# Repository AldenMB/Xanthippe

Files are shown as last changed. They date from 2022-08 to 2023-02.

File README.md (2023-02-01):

# Xanthippe

an animated GIF of the Xanthippe circuit running

This is the validation back-end for my TI-30Xa emulator. It is constantly pressing buttons on a TI-30Xa calculator and recording what the LCD shows. The results get stored in an SQLite database. The database is too big to be stored on github, but you can download a CSV from [https://home.aldenbradford.com:58086/](https://home.aldenbradford.com:58086/). In addition, whenever anyone uses the calculator at [https://aldenbradford.com/calculator_emulator/](https://aldenbradford.com/calculator_emulator/) the sequence of button presses is sent to Xanthippe to be tested. It will show up in the database the following day.

For more information about this project, [please see my blog](https://aldenbradford.com/tag/xanthippe.html).

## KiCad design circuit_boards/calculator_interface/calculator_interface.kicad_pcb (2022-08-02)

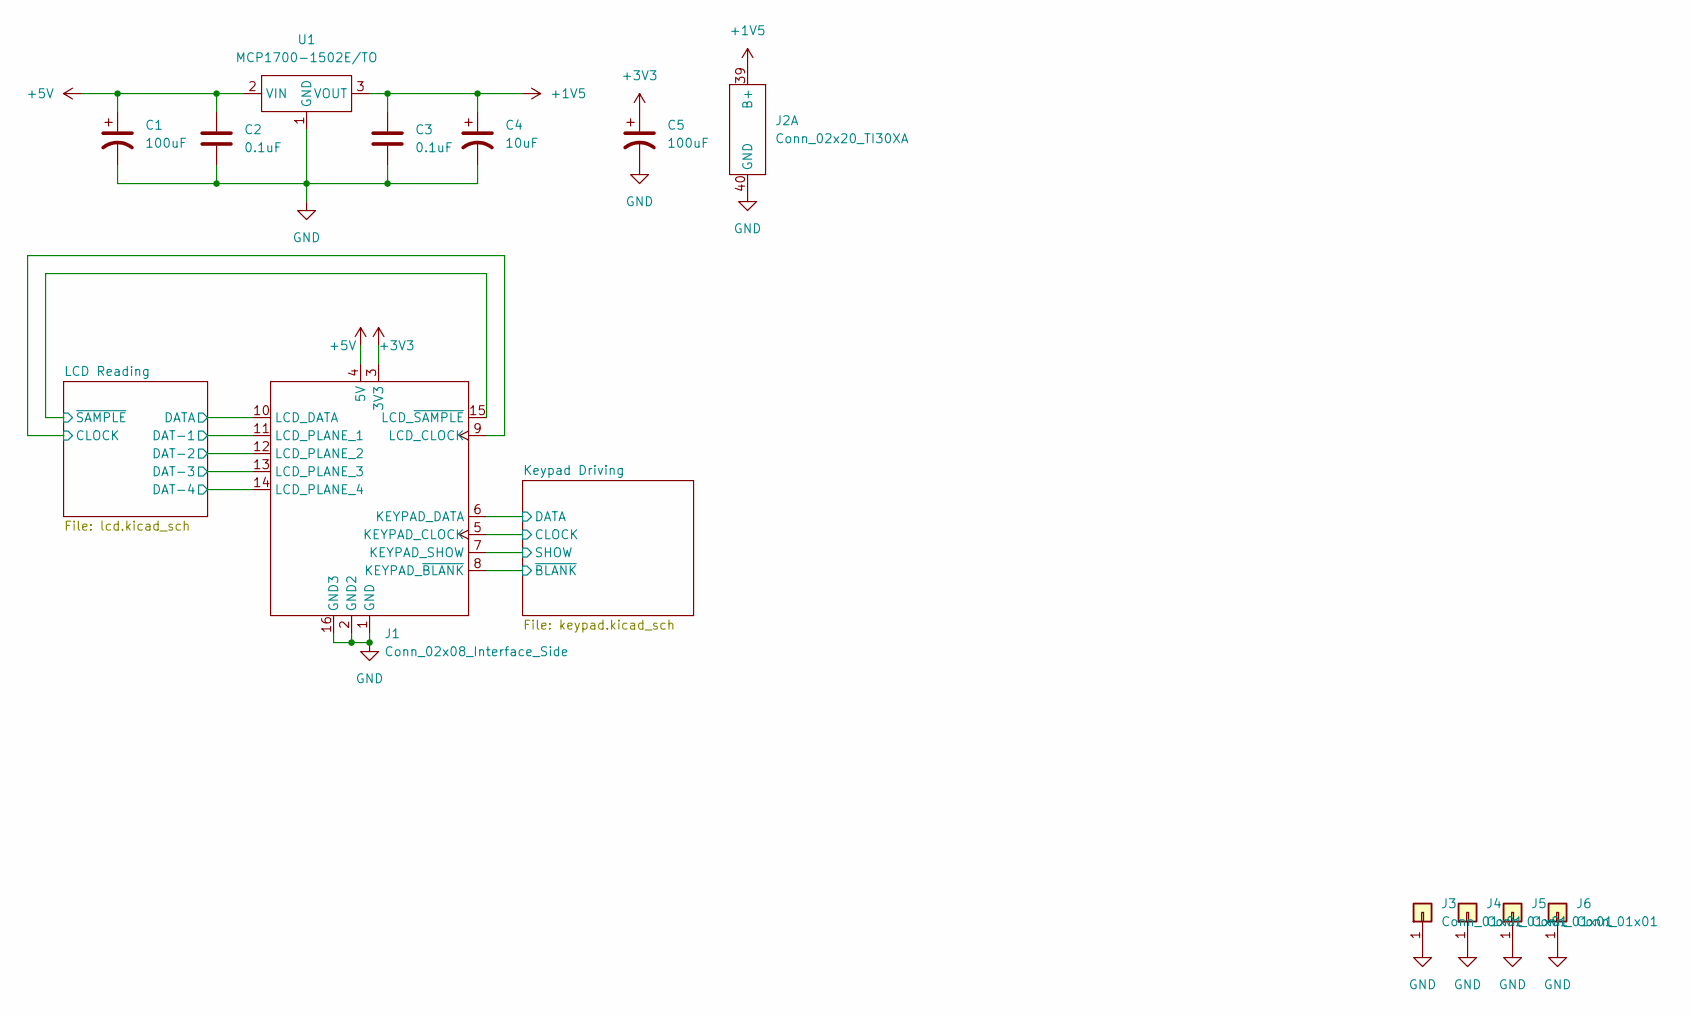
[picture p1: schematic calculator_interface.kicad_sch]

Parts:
C1, C5: 100uF; CP_Radial_D5.0mm_P2.50mm
C2, C3: 0.1uF; C_Disc_D3.8mm_W2.6mm_P2.50mm
C4: 10uF; CP_Radial_D4.0mm_P2.00mm
J1: Conn_02x08_Interface_Side; IDC-Header_2x08_P2.54mm_Vertical
J2: Conn_02x20_TI30XA; IDC-Header_2x20_P2.54mm_Vertical
J3, J4, J5, J6: Conn_01x01; MountingHole_5mm_Pad_Via
U1: MCP1700-1502E/TO; TO-92_Inline

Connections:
+1V5: C3.1, C4.1, J2.39 (B+), U1.3 (VOUT); also elsewhere on the board
+3V3: C5.1, J1.3 (3V3); also elsewhere on the board
+5V: C1.1, C2.1, J1.4 (5V), U1.2 (VIN); also elsewhere on the board
/Keypad Driving/CLOCK: J1.5 (KEYPAD_CLOCK); also elsewhere on the board
/Keypad Driving/DATA: J1.6 (KEYPAD_DATA); also elsewhere on the board
/Keypad Driving/SHOW: J1.7 (KEYPAD_SHOW); also elsewhere on the board
/Keypad Driving/~BLANK: J1.8 (KEYPAD_~BLANK); also elsewhere on the board
/LCD Reading/CLOCK: J1.9 (LCD_CLOCK); also elsewhere on the board
/LCD Reading/DAT-1: J1.11 (LCD_PLANE_1); also elsewhere on the board
/LCD Reading/DAT-2: J1.12 (LCD_PLANE_2); also elsewhere on the board
/LCD Reading/DAT-3: J1.13 (LCD_PLANE_3); also elsewhere on the board
/LCD Reading/DAT-4: J1.14 (LCD_PLANE_4); also elsewhere on the board
/LCD Reading/DATA: J1.10 (LCD_DATA); also elsewhere on the board
/LCD Reading/~SAMPLE: J1.15 (LCD_~SAMPLE); also elsewhere on the board
GND: C1.2, C2.2, C3.2, C4.2, C5.2, J1.1 (GND), J1.2 (GND2), J1.16 (GND3), J2.40 (GND), J3.1, J4.1, J5.1, J6.1, U1.1 (GND); also elsewhere on the board

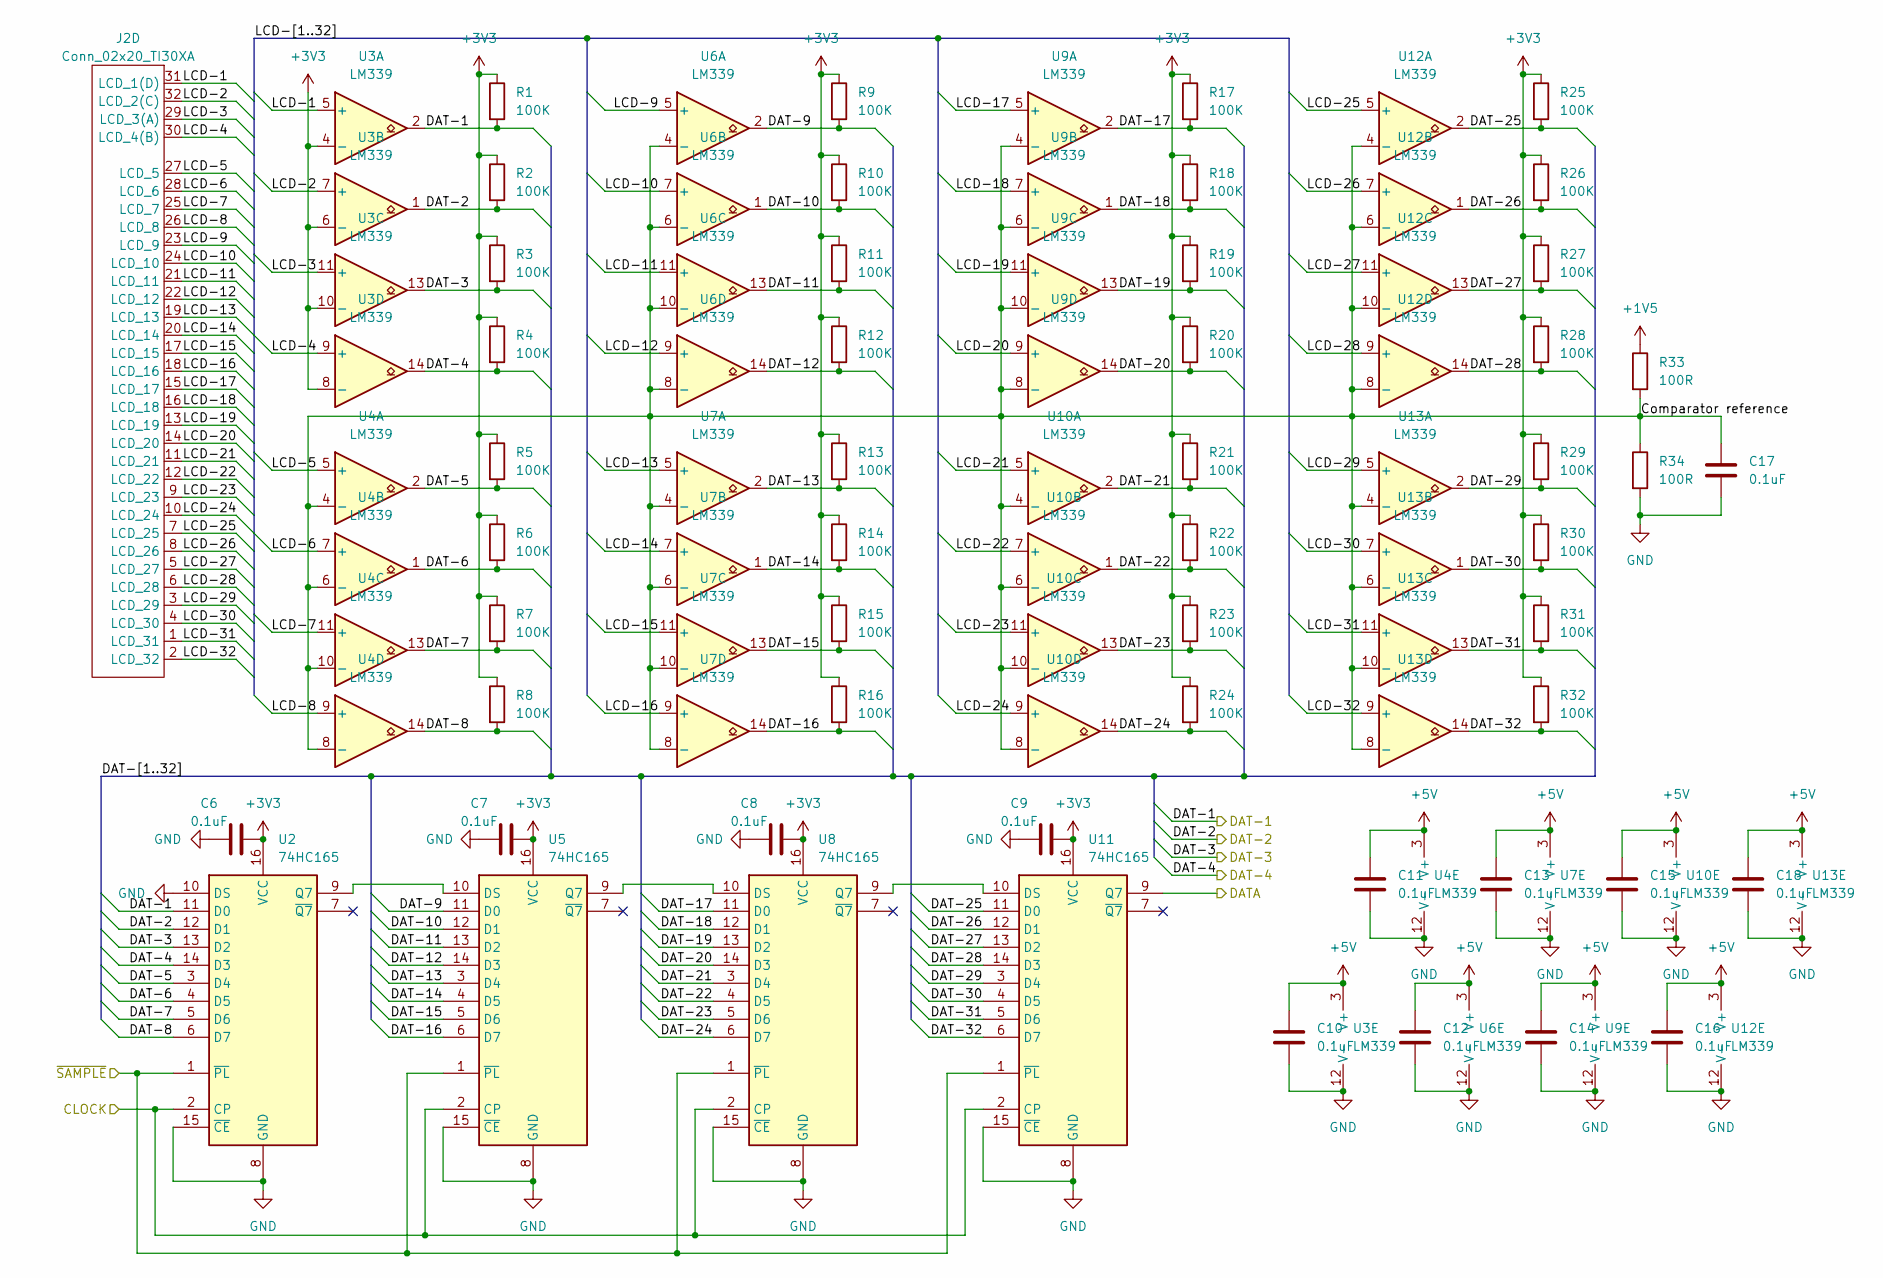
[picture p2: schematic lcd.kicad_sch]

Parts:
C6, C7, C8, C9, C10, C11, C12, C13, C14, C15, C16, C17, C18: 0.1uF; C_Disc_D3.8mm_W2.6mm_P2.50mm
J2: Conn_02x20_TI30XA; IDC-Header_2x20_P2.54mm_Vertical
R1, R2, R3, R4, R5, R6, R7, R8, R9, R10, R11, R12, R13, R14, R15, R16, R17, R18, R19, R20, R21, R22, R23, R24, R25, R26, R27, R28, R29, R30, R31, R32: 100K; R_Axial_DIN0204_L3.6mm_D1.6mm_P7.62mm_Horizontal
R33, R34: 100R; R_Axial_DIN0207_L6.3mm_D2.5mm_P10.16mm_Horizontal
U2, U5, U8, U11: 74HC165; DIP-16_W7.62mm_LongPads
U3, U4, U6, U7, U9, U10, U12, U13: LM339; DIP-14_W7.62mm_LongPads

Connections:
+1V5: R33.1; also elsewhere on the board
+3V3: C6.2, C7.2, C8.2, C9.2, R1.1, R2.1, R3.1, R4.1, R5.1, R6.1, R7.1, R8.1, R9.1, R10.1, R11.1, R12.1, R13.1, R14.1, R15.1, R16.1, R17.1, R18.1, R19.1, R20.1, R21.1, R22.1, R23.1, R24.1, R25.1, R26.1, R27.1, R28.1, R29.1, R30.1, R31.1, R32.1, U2.16 (VCC), U3.4 (-), U3.6 (-), U3.8 (-), U3.10 (-), U5.16 (VCC), U8.16 (VCC), U11.16 (VCC); also elsewhere on the board
+5V: C10.1, C11.1, C12.1, C13.1, C14.1, C15.1, C16.1, C18.1, U3.3 (V+), U4.3 (V+), U6.3 (V+), U7.3 (V+), U9.3 (V+), U10.3 (V+), U12.3 (V+), U13.3 (V+); also elsewhere on the board
/LCD Reading/CLOCK: U2.2 (CP), U5.2 (CP), U8.2 (CP), U11.2 (CP); also elsewhere on the board
/LCD Reading/Comparator reference: C17.1, R33.2, R34.1, U4.4 (-), U4.6 (-), U4.8 (-), U4.10 (-), U6.4 (-), U6.6 (-), U6.8 (-), U6.10 (-), U7.4 (-), U7.6 (-), U7.8 (-), U7.10 (-), U9.4 (-), U9.6 (-), U9.8 (-), U9.10 (-), U10.4 (-), U10.6 (-), U10.8 (-), U10.10 (-), U12.4 (-), U12.6 (-), U12.8 (-), U12.10 (-), U13.4 (-), U13.6 (-), U13.8 (-), U13.10 (-)
/LCD Reading/DAT-1: R1.2, U2.11 (D0), U3.2; also elsewhere on the board
/LCD Reading/DAT-2: R2.2, U2.12 (D1), U3.1; also elsewhere on the board
/LCD Reading/DAT-3: R3.2, U2.13 (D2), U3.13; also elsewhere on the board
/LCD Reading/DAT-4: R4.2, U2.14 (D3), U3.14; also elsewhere on the board
/LCD Reading/DAT-5: R5.2, U2.3 (D4), U4.2
/LCD Reading/DAT-6: R6.2, U2.4 (D5), U4.1
/LCD Reading/DAT-7: R7.2, U2.5 (D6), U4.13
/LCD Reading/DAT-8: R8.2, U2.6 (D7), U4.14
/LCD Reading/DAT-9: R9.2, U5.11 (D0), U6.2
/LCD Reading/DAT-10: R10.2, U5.12 (D1), U6.1
/LCD Reading/DAT-11: R11.2, U5.13 (D2), U6.13
/LCD Reading/DAT-12: R12.2, U5.14 (D3), U6.14
/LCD Reading/DAT-13: R13.2, U5.3 (D4), U7.2
/LCD Reading/DAT-14: R14.2, U5.4 (D5), U7.1
/LCD Reading/DAT-15: R15.2, U5.5 (D6), U7.13
/LCD Reading/DAT-16: R16.2, U5.6 (D7), U7.14
/LCD Reading/DAT-17: R17.2, U8.11 (D0), U9.2
/LCD Reading/DAT-18: R18.2, U8.12 (D1), U9.1
/LCD Reading/DAT-19: R19.2, U8.13 (D2), U9.13
/LCD Reading/DAT-20: R20.2, U8.14 (D3), U9.14
/LCD Reading/DAT-21: R21.2, U8.3 (D4), U10.2
/LCD Reading/DAT-22: R22.2, U8.4 (D5), U10.1
/LCD Reading/DAT-23: R23.2, U8.5 (D6), U10.13
/LCD Reading/DAT-24: R24.2, U8.6 (D7), U10.14
/LCD Reading/DAT-25: R25.2, U11.11 (D0), U12.2
/LCD Reading/DAT-26: R26.2, U11.12 (D1), U12.1
/LCD Reading/DAT-27: R27.2, U11.13 (D2), U12.13
/LCD Reading/DAT-28: R28.2, U11.14 (D3), U12.14
/LCD Reading/DAT-29: R29.2, U11.3 (D4), U13.2
/LCD Reading/DAT-30: R30.2, U11.4 (D5), U13.1
/LCD Reading/DAT-31: R31.2, U11.5 (D6), U13.13
/LCD Reading/DAT-32: R32.2, U11.6 (D7), U13.14
/LCD Reading/DATA: U11.9 (Q7); also elsewhere on the board
/LCD Reading/LCD-1: J2.31 (LCD_1(D)), U3.5 (+)
/LCD Reading/LCD-2: J2.32 (LCD_2(C)), U3.7 (+)
/LCD Reading/LCD-3: J2.29 (LCD_3(A)), U3.11 (+)
/LCD Reading/LCD-4: J2.30 (LCD_4(B)), U3.9 (+)
/LCD Reading/LCD-5: J2.27 (LCD_5), U4.5 (+)
/LCD Reading/LCD-6: J2.28 (LCD_6), U4.7 (+)
/LCD Reading/LCD-7: J2.25 (LCD_7), U4.11 (+)
/LCD Reading/LCD-8: J2.26 (LCD_8), U4.9 (+)
/LCD Reading/LCD-9: J2.23 (LCD_9), U6.5 (+)
/LCD Reading/LCD-10: J2.24 (LCD_10), U6.7 (+)
/LCD Reading/LCD-11: J2.21 (LCD_11), U6.11 (+)
/LCD Reading/LCD-12: J2.22 (LCD_12), U6.9 (+)
/LCD Reading/LCD-13: J2.19 (LCD_13), U7.5 (+)
/LCD Reading/LCD-14: J2.20 (LCD_14), U7.7 (+)
/LCD Reading/LCD-15: J2.17 (LCD_15), U7.11 (+)
/LCD Reading/LCD-16: J2.18 (LCD_16), U7.9 (+)
/LCD Reading/LCD-17: J2.15 (LCD_17), U9.5 (+)
/LCD Reading/LCD-18: J2.16 (LCD_18), U9.7 (+)
/LCD Reading/LCD-19: J2.13 (LCD_19), U9.11 (+)
/LCD Reading/LCD-20: J2.14 (LCD_20), U9.9 (+)
/LCD Reading/LCD-21: J2.11 (LCD_21), U10.5 (+)
/LCD Reading/LCD-22: J2.12 (LCD_22), U10.7 (+)
/LCD Reading/LCD-23: J2.9 (LCD_23), U10.11 (+)
/LCD Reading/LCD-24: J2.10 (LCD_24), U10.9 (+)
/LCD Reading/LCD-25: J2.7 (LCD_25), U12.5 (+)
/LCD Reading/LCD-26: J2.8 (LCD_26), U12.7 (+)
/LCD Reading/LCD-27: J2.5 (LCD_27), U12.11 (+)
/LCD Reading/LCD-28: J2.6 (LCD_28), U12.9 (+)
/LCD Reading/LCD-29: J2.3 (LCD_29), U13.5 (+)
/LCD Reading/LCD-30: J2.4 (LCD_30), U13.7 (+)
/LCD Reading/LCD-31: J2.1 (LCD_31), U13.11 (+)
/LCD Reading/LCD-32: J2.2 (LCD_32), U13.9 (+)
/LCD Reading/~SAMPLE: U2.1 (~PL), U5.1 (~PL), U8.1 (~PL), U11.1 (~PL); also elsewhere on the board
GND: C6.1, C7.1, C8.1, C9.1, C10.2, C11.2, C12.2, C13.2, C14.2, C15.2, C16.2, C17.2, C18.2, R34.2, U2.8 (GND), U2.10 (DS), U2.15 (~CE), U3.12 (V-), U4.12 (V-), U5.8 (GND), U5.15 (~CE), U6.12 (V-), U7.12 (V-), U8.8 (GND), U8.15 (~CE), U9.12 (V-), U10.12 (V-), U11.8 (GND), U11.15 (~CE), U12.12 (V-), U13.12 (V-); also elsewhere on the board
unnamed: U2.9 (Q7), U5.10 (DS)
unnamed: U5.9 (Q7), U8.10 (DS)
unnamed: U8.9 (Q7), U11.10 (DS)

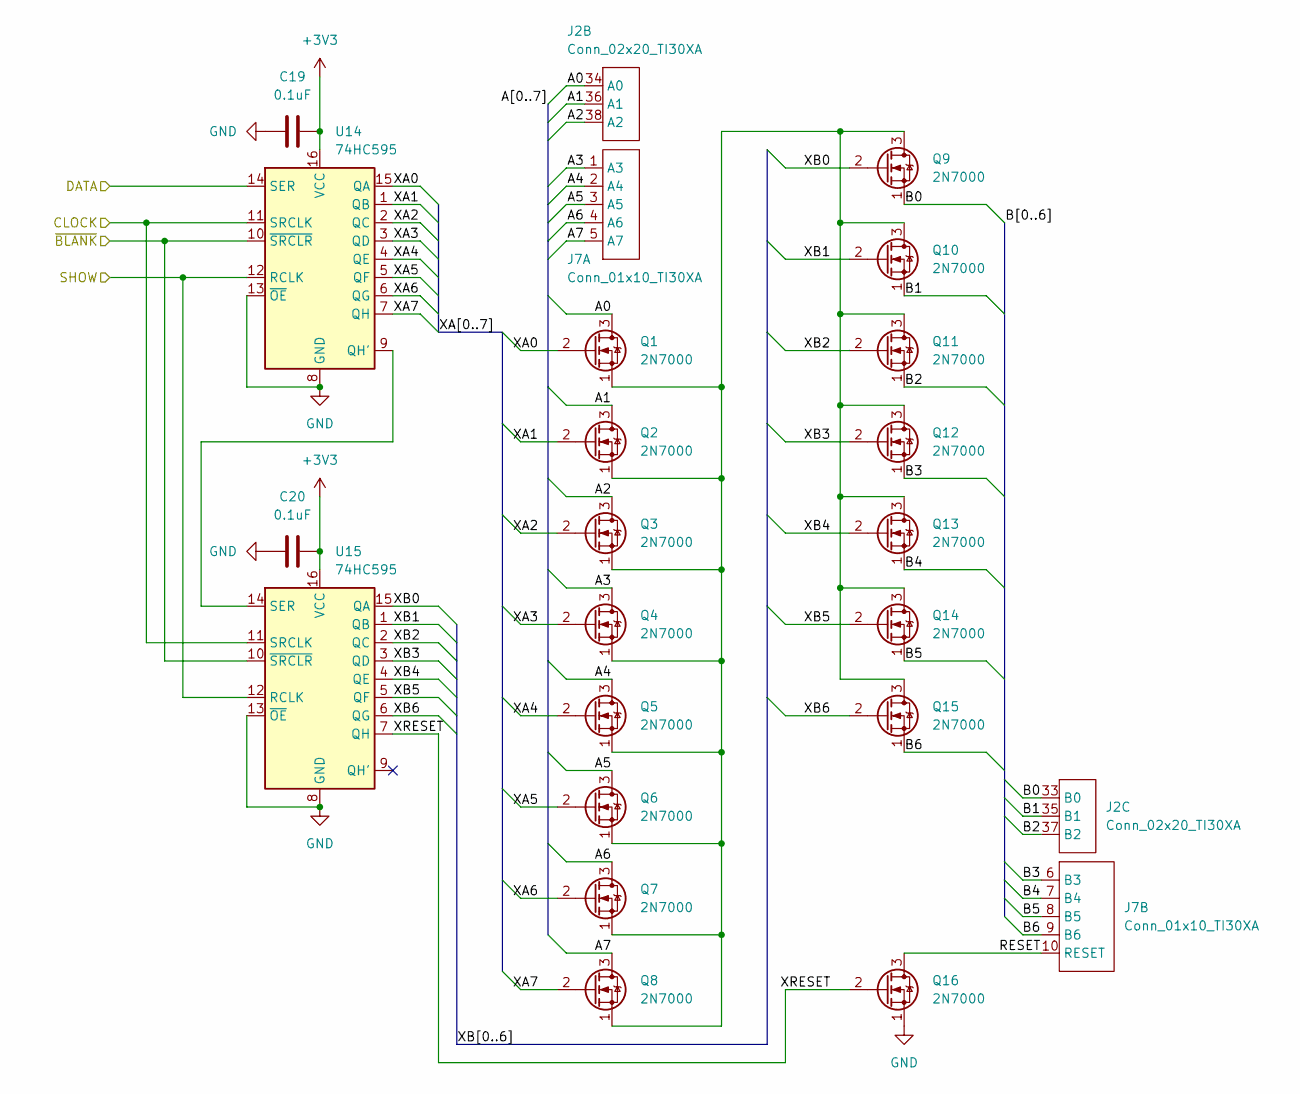
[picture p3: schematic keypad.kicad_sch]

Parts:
C19, C20: 0.1uF; C_Disc_D3.8mm_W2.6mm_P2.50mm
J2: Conn_02x20_TI30XA; IDC-Header_2x20_P2.54mm_Vertical
J7: Conn_01x10_TI30XA; PinHeader_1x10_P2.54mm_Horizontal
Q1, Q2, Q3, Q4, Q5, Q6, Q7, Q8, Q9, Q10, Q11, Q12, Q13, Q14, Q15, Q16: 2N7000; TO-92_Inline
U14, U15: 74HC595; DIP-16_W7.62mm_LongPads

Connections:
+3V3: C19.2, C20.1, U14.16 (VCC), U15.16 (VCC); also elsewhere on the board
/Keypad Driving/A0: J2.34 (A0), Q1.3 (D)
/Keypad Driving/A1: J2.36 (A1), Q2.3 (D)
/Keypad Driving/A2: J2.38 (A2), Q3.3 (D)
/Keypad Driving/A3: J7.1 (A3), Q4.3 (D)
/Keypad Driving/A4: J7.2 (A4), Q5.3 (D)
/Keypad Driving/A5: J7.3 (A5), Q6.3 (D)
/Keypad Driving/A6: J7.4 (A6), Q7.3 (D)
/Keypad Driving/A7: J7.5 (A7), Q8.3 (D)
/Keypad Driving/B0: J2.33 (B0), Q9.1 (S)
/Keypad Driving/B1: J2.35 (B1), Q10.1 (S)
/Keypad Driving/B2: J2.37 (B2), Q11.1 (S)
/Keypad Driving/B3: J7.6 (B3), Q12.1 (S)
/Keypad Driving/B4: J7.7 (B4), Q13.1 (S)
/Keypad Driving/B5: J7.8 (B5), Q14.1 (S)
/Keypad Driving/B6: J7.9 (B6), Q15.1 (S)
/Keypad Driving/CLOCK: U14.11 (SRCLK), U15.11 (SRCLK); also elsewhere on the board
/Keypad Driving/DATA: U14.14 (SER); also elsewhere on the board
/Keypad Driving/RESET: J7.10 (RESET), Q16.3 (D)
/Keypad Driving/SHOW: U14.12 (RCLK), U15.12 (RCLK); also elsewhere on the board
/Keypad Driving/XA0: Q1.2 (G), U14.15 (QA)
/Keypad Driving/XA1: Q2.2 (G), U14.1 (QB)
/Keypad Driving/XA2: Q3.2 (G), U14.2 (QC)
/Keypad Driving/XA3: Q4.2 (G), U14.3 (QD)
/Keypad Driving/XA4: Q5.2 (G), U14.4 (QE)
/Keypad Driving/XA5: Q6.2 (G), U14.5 (QF)
/Keypad Driving/XA6: Q7.2 (G), U14.6 (QG)
/Keypad Driving/XA7: Q8.2 (G), U14.7 (QH)
/Keypad Driving/XB0: Q9.2 (G), U15.15 (QA)
/Keypad Driving/XB1: Q10.2 (G), U15.1 (QB)
/Keypad Driving/XB2: Q11.2 (G), U15.2 (QC)
/Keypad Driving/XB3: Q12.2 (G), U15.3 (QD)
/Keypad Driving/XB4: Q13.2 (G), U15.4 (QE)
/Keypad Driving/XB5: Q14.2 (G), U15.5 (QF)
/Keypad Driving/XB6: Q15.2 (G), U15.6 (QG)
/Keypad Driving/XRESET: Q16.2 (G), U15.7 (QH)
/Keypad Driving/~BLANK: U14.10 (~SRCLR), U15.10 (~SRCLR); also elsewhere on the board
GND: C19.1, C20.2, Q16.1 (S), U14.8 (GND), U14.13 (~OE), U15.8 (GND), U15.13 (~OE); also elsewhere on the board
unnamed: Q1.1 (S), Q2.1 (S), Q3.1 (S), Q4.1 (S), Q5.1 (S), Q6.1 (S), Q7.1 (S), Q8.1 (S), Q9.3 (D), Q10.3 (D), Q11.3 (D), Q12.3 (D), Q13.3 (D), Q14.3 (D), Q15.3 (D)
unnamed: U14.9 (QH'), U15.14 (SER)

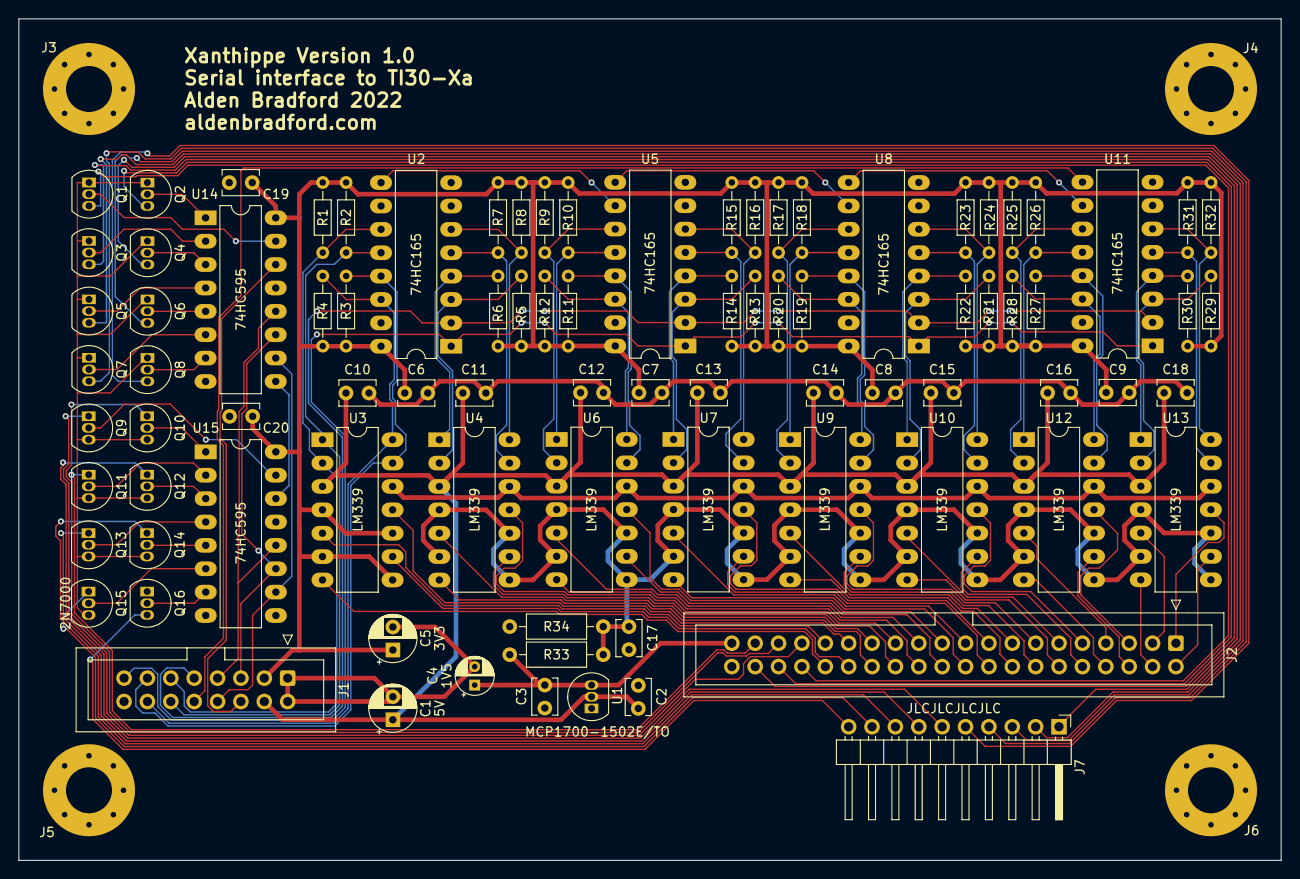
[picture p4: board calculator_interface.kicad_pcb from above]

Board: 2 copper layers, 137.2 x 91.4 mm, 92 parts (0 on the bottom side), 113 nets.

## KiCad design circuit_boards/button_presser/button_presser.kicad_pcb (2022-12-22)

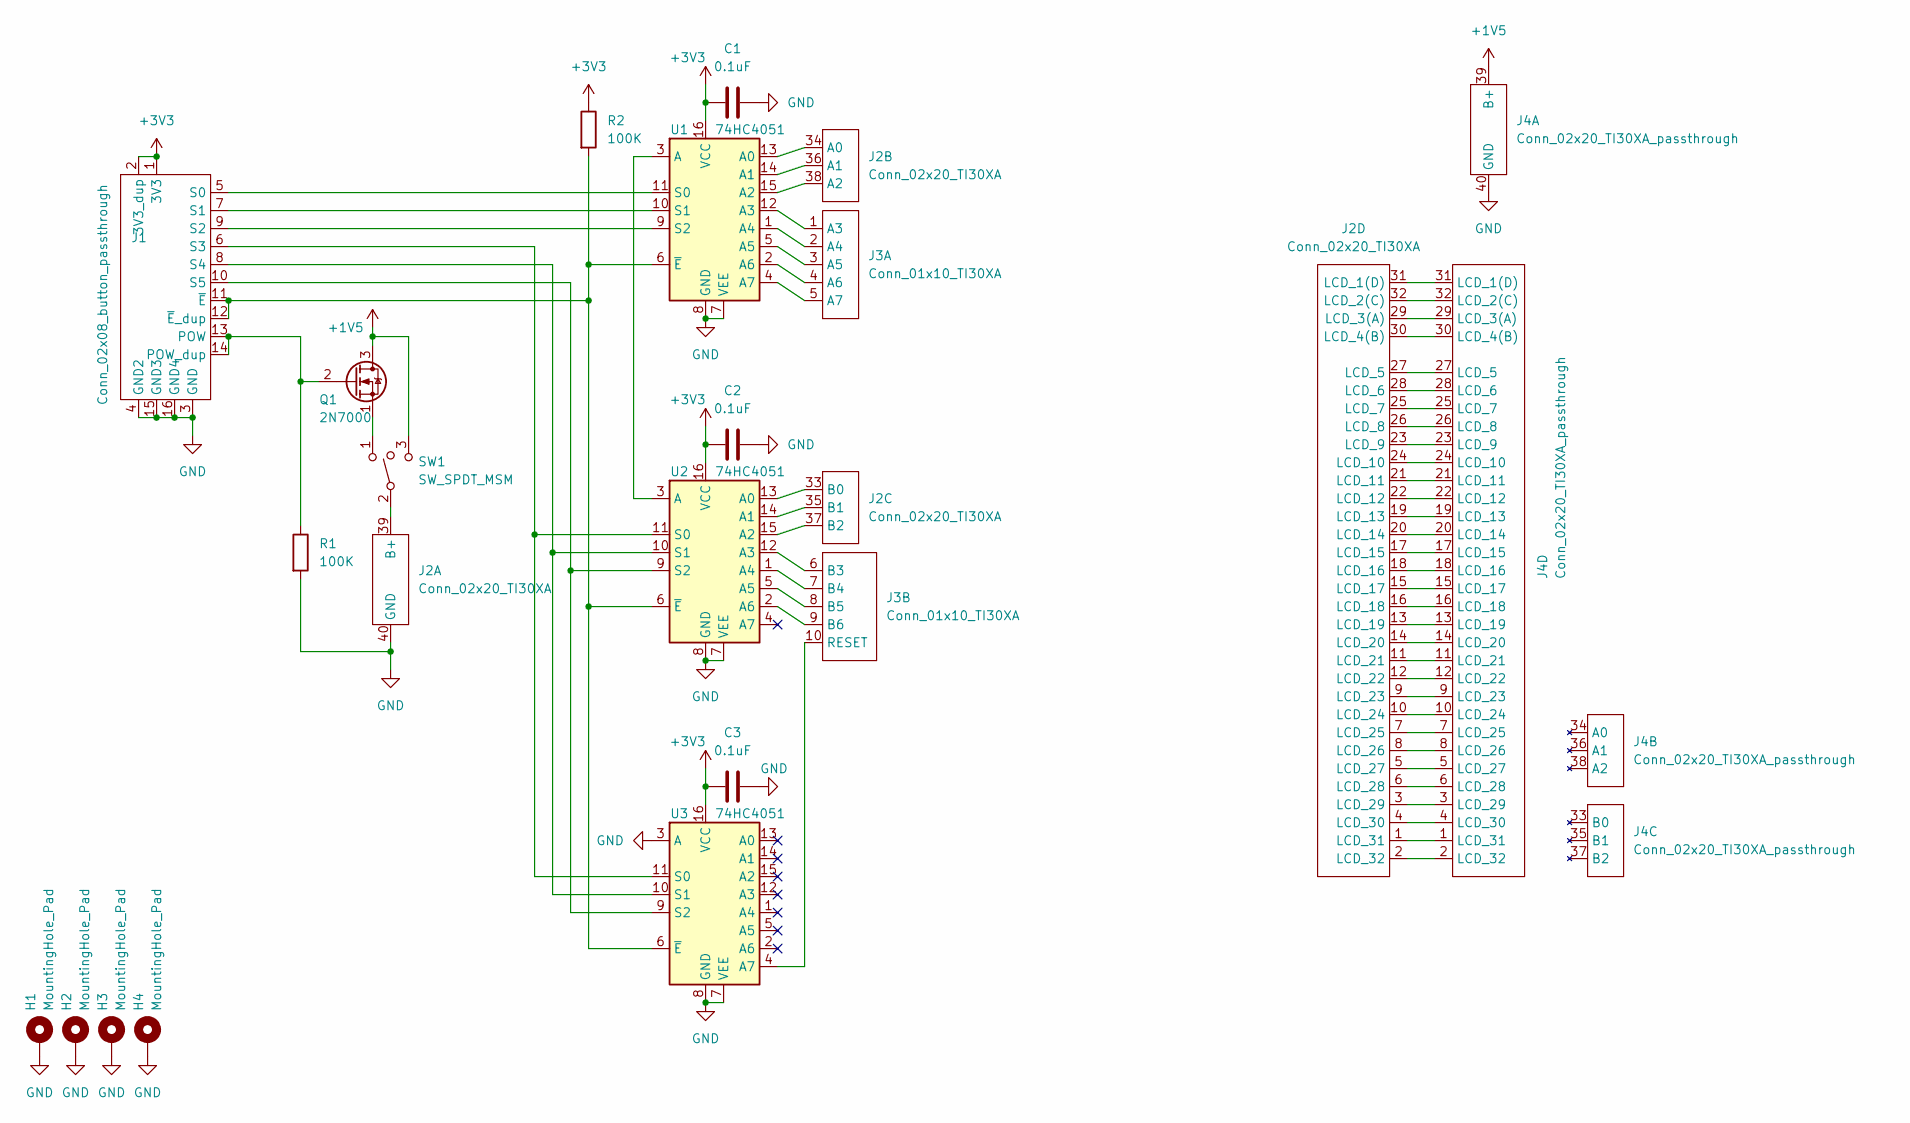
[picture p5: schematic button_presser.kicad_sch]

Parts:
C1, C2, C3: 0.1uF; C_Disc_D5.0mm_W2.5mm_P2.50mm
H1, H2, H3, H4: MountingHole_Pad; MountingHole_5mm_Pad_Via
J1: Conn_02x08_button_passthrough; IDC-Header_2x08_P2.54mm_Vertical
J2: Conn_02x20_TI30XA; IDC-Header_2x20_P2.54mm_Vertical
J3: Conn_01x10_TI30XA; PinHeader_1x10_P2.54mm_Horizontal
J4: Conn_02x20_TI30XA_passthrough; IDC-Header_2x20_P2.54mm_Vertical
Q1: 2N7000; TO-92_Inline_Wide
R1, R2: 100K; R_Axial_DIN0411_L9.9mm_D3.6mm_P15.24mm_Horizontal
SW1: SW_SPDT_MSM; Switch_Jumper
U1, U2, U3: 74HC4051; DIP-16_W7.62mm_LongPads

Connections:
+1V5: J4.39 (B+), Q1.3 (D), SW1.3
+3V3: C1.1, C2.1, C3.1, J1.1 (3V3), J1.2 (3V3_dup), R2.1, U1.16 (VCC), U2.16 (VCC), U3.16 (VCC)
GND: C1.2, C2.2, C3.2, H1.1, H2.1, H3.1, H4.1, J1.3 (GND), J1.4 (GND2), J1.15 (GND3), J1.16 (GND4), J2.40 (GND), J4.40 (GND), R1.2, U1.7 (VEE), U1.8 (GND), U2.7 (VEE), U2.8 (GND), U3.3 (A), U3.7 (VEE), U3.8 (GND)
unnamed: J1.5 (S0), U1.11 (S0)
unnamed: J1.6 (S3), U2.11 (S0), U3.11 (S0)
unnamed: J1.7 (S1), U1.10 (S1)
unnamed: J1.8 (S4), U2.10 (S1), U3.10 (S1)
unnamed: J1.9 (S2), U1.9 (S2)
unnamed: J1.10 (S5), U2.9 (S2), U3.9 (S2)
unnamed: J1.11 (~E), J1.12 (~E_dup), R2.2, U1.6 (~E), U2.6 (~E), U3.6 (~E)
unnamed: J1.13 (POW), J1.14 (POW_dup), Q1.2 (G), R1.1
unnamed: J2.1 (LCD_31), J4.1 (LCD_31)
unnamed: J2.2 (LCD_32), J4.2 (LCD_32)
unnamed: J2.3 (LCD_29), J4.3 (LCD_29)
unnamed: J2.4 (LCD_30), J4.4 (LCD_30)
unnamed: J2.5 (LCD_27), J4.5 (LCD_27)
unnamed: J2.6 (LCD_28), J4.6 (LCD_28)
unnamed: J2.7 (LCD_25), J4.7 (LCD_25)
unnamed: J2.8 (LCD_26), J4.8 (LCD_26)
unnamed: J2.9 (LCD_23), J4.9 (LCD_23)
unnamed: J2.10 (LCD_24), J4.10 (LCD_24)
unnamed: J2.11 (LCD_21), J4.11 (LCD_21)
unnamed: J2.12 (LCD_22), J4.12 (LCD_22)
unnamed: J2.13 (LCD_19), J4.13 (LCD_19)
unnamed: J2.14 (LCD_20), J4.14 (LCD_20)
unnamed: J2.15 (LCD_17), J4.15 (LCD_17)
unnamed: J2.16 (LCD_18), J4.16 (LCD_18)
unnamed: J2.17 (LCD_15), J4.17 (LCD_15)
unnamed: J2.18 (LCD_16), J4.18 (LCD_16)
unnamed: J2.19 (LCD_13), J4.19 (LCD_13)
unnamed: J2.20 (LCD_14), J4.20 (LCD_14)
unnamed: J2.21 (LCD_11), J4.21 (LCD_11)
unnamed: J2.22 (LCD_12), J4.22 (LCD_12)
unnamed: J2.23 (LCD_9), J4.23 (LCD_9)
unnamed: J2.24 (LCD_10), J4.24 (LCD_10)
unnamed: J2.25 (LCD_7), J4.25 (LCD_7)
unnamed: J2.26 (LCD_8), J4.26 (LCD_8)
unnamed: J2.27 (LCD_5), J4.27 (LCD_5)
unnamed: J2.28 (LCD_6), J4.28 (LCD_6)
unnamed: J2.29 (LCD_3(A)), J4.29 (LCD_3(A))
unnamed: J2.30 (LCD_4(B)), J4.30 (LCD_4(B))
unnamed: J2.31 (LCD_1(D)), J4.31 (LCD_1(D))
unnamed: J2.32 (LCD_2(C)), J4.32 (LCD_2(C))
unnamed: J2.33 (B0), U2.13 (A0)
unnamed: J2.34 (A0), U1.13 (A0)
unnamed: J2.35 (B1), U2.14 (A1)
unnamed: J2.36 (A1), U1.14 (A1)
unnamed: J2.37 (B2), U2.15 (A2)
unnamed: J2.38 (A2), U1.15 (A2)
unnamed: J2.39 (B+), SW1.2
unnamed: J3.1 (A3), U1.12 (A3)
unnamed: J3.2 (A4), U1.1 (A4)
unnamed: J3.3 (A5), U1.5 (A5)
unnamed: J3.4 (A6), U1.2 (A6)
unnamed: J3.5 (A7), U1.4 (A7)
unnamed: J3.6 (B3), U2.12 (A3)
unnamed: J3.7 (B4), U2.1 (A4)
unnamed: J3.8 (B5), U2.5 (A5)
unnamed: J3.9 (B6), U2.2 (A6)
unnamed: J3.10 (RESET), U3.4 (A7)
unnamed: Q1.1 (S), SW1.1
unnamed: U1.3 (A), U2.3 (A)

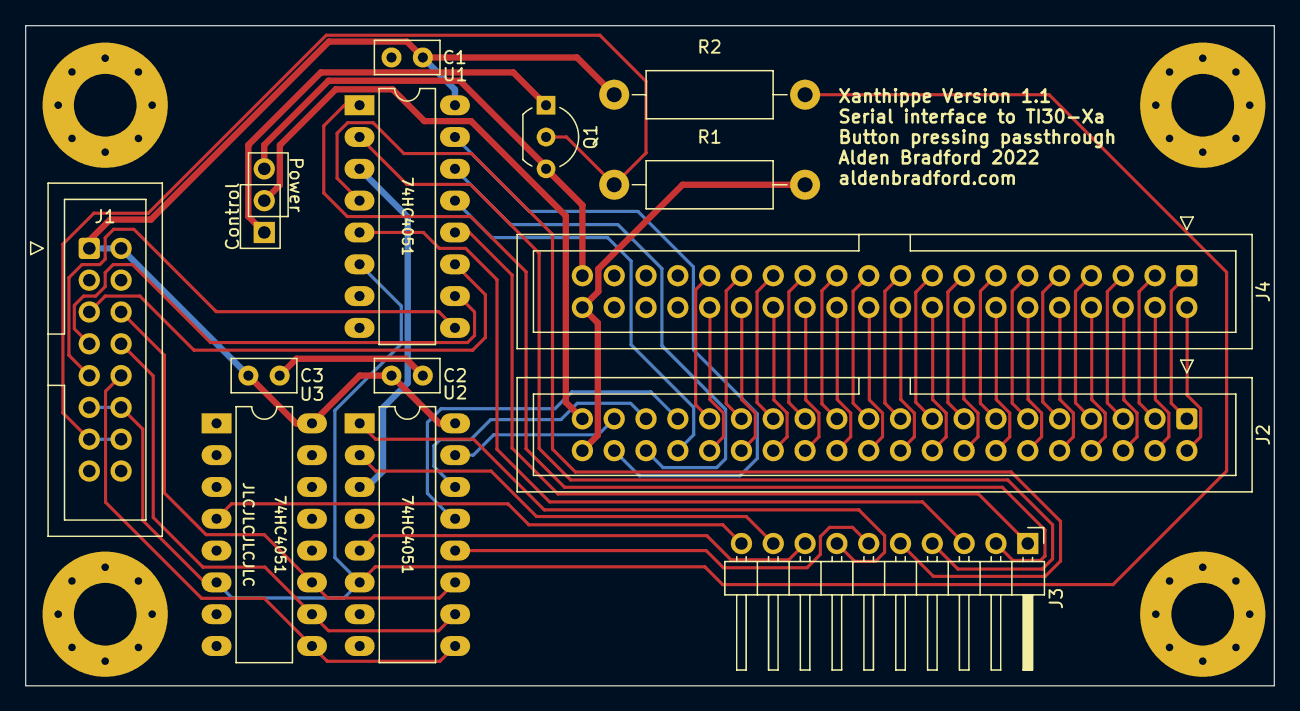
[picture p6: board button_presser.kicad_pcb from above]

Board: 2 copper layers, 99.7 x 52.7 mm, 18 parts (0 on the bottom side), 62 nets.

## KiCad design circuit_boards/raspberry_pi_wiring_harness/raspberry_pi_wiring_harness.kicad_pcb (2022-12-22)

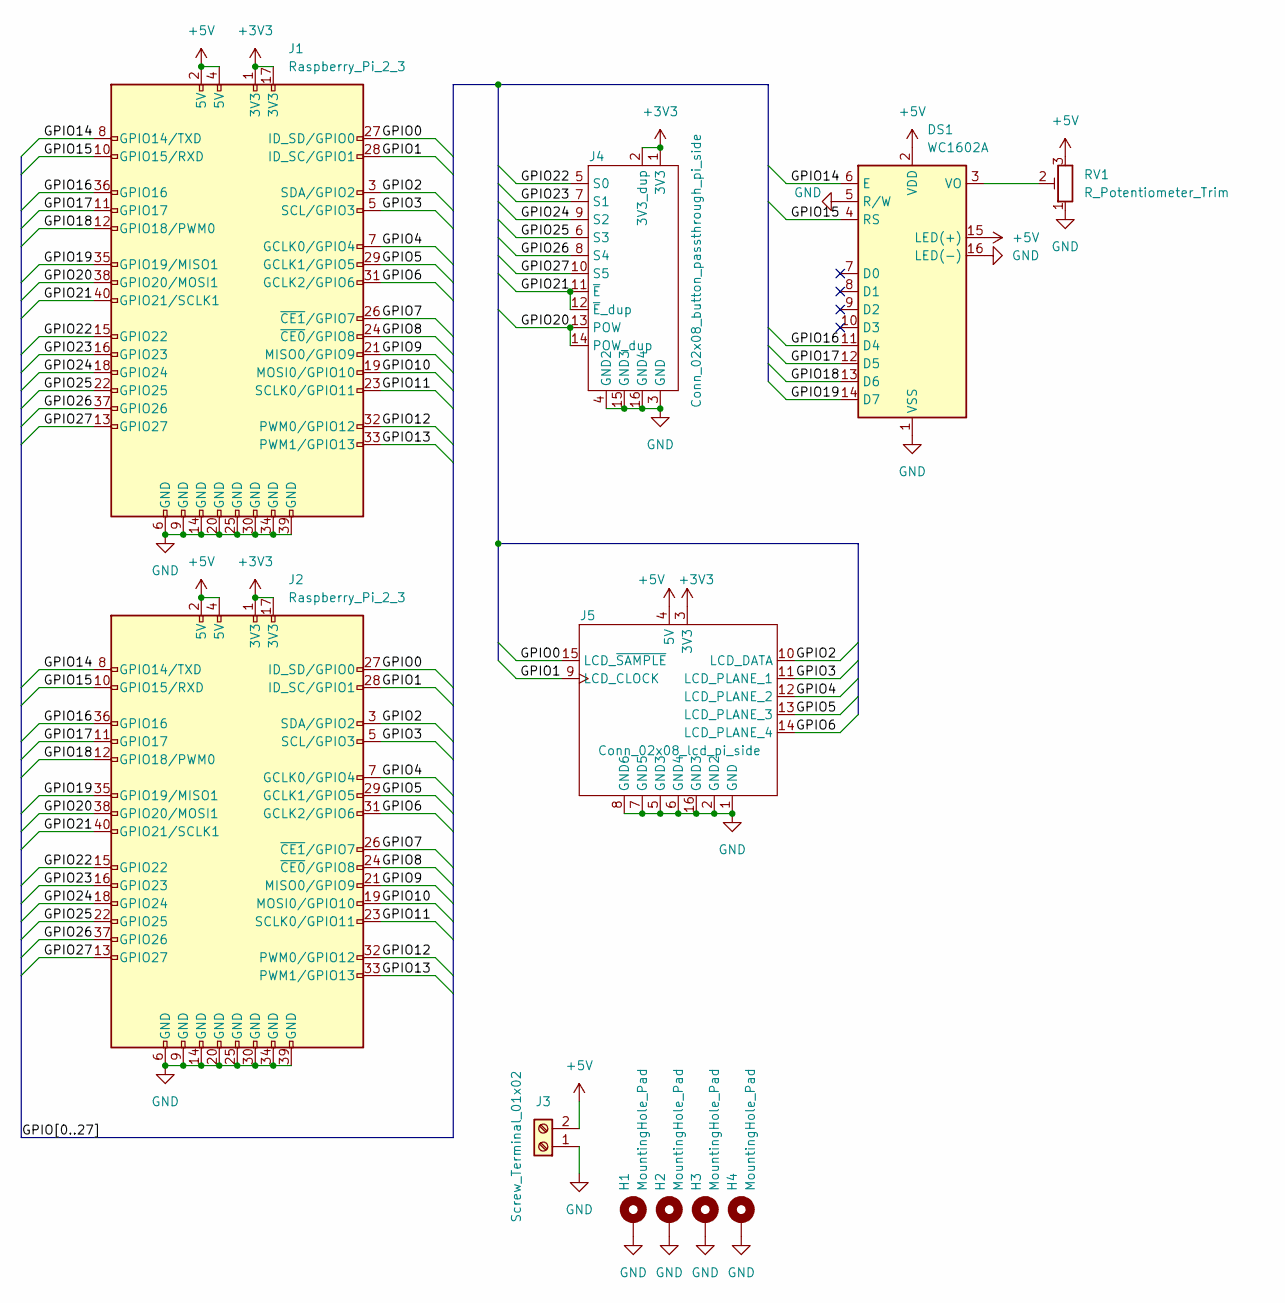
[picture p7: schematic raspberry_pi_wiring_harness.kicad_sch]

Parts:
DS1: WC1602A
H1, H2, H3, H4: MountingHole_Pad; MountingHole_5mm_Pad_Via
J1, J2: Raspberry_Pi_2_3; IDC-Header_2x20_P2.54mm_Vertical
J3: Screw_Terminal_01x02; TerminalBlock_bornier-2_P5.08mm
J4: Conn_02x08_button_passthrough_pi_side; IDC-Header_2x08_P2.54mm_Vertical
J5: Conn_02x08_lcd_pi_side; IDC-Header_2x08_P2.54mm_Vertical
RV1: R_Potentiometer_Trim; Potentiometer_Bourns_3296W_Vertical

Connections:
+3V3: J1.1 (3V3), J1.17 (3V3), J2.1 (3V3), J2.17 (3V3), J4.1 (3V3), J4.2 (3V3_dup), J5.3 (3V3)
+5V: DS1.2 (VDD), DS1.15 (LED(+)), J1.2 (5V), J1.4 (5V), J2.2 (5V), J2.4 (5V), J3.2, J5.4 (5V), RV1.3
/GPIO0: J1.27 (ID_SD/GPIO0), J2.27 (ID_SD/GPIO0), J5.15 (LCD_~SAMPLE)
/GPIO1: J1.28 (ID_SC/GPIO1), J2.28 (ID_SC/GPIO1), J5.9 (LCD_CLOCK)
/GPIO2: J1.3 (SDA/GPIO2), J2.3 (SDA/GPIO2), J5.10 (LCD_DATA)
/GPIO3: J1.5 (SCL/GPIO3), J2.5 (SCL/GPIO3), J5.11 (LCD_PLANE_1)
/GPIO4: J1.7 (GCLK0/GPIO4), J2.7 (GCLK0/GPIO4), J5.12 (LCD_PLANE_2)
/GPIO5: J1.29 (GCLK1/GPIO5), J2.29 (GCLK1/GPIO5), J5.13 (LCD_PLANE_3)
/GPIO6: J1.31 (GCLK2/GPIO6), J2.31 (GCLK2/GPIO6), J5.14 (LCD_PLANE_4)
/GPIO7: J1.26 (~CE1/GPIO7), J2.26 (~CE1/GPIO7)
/GPIO8: J1.24 (~CE0/GPIO8), J2.24 (~CE0/GPIO8)
/GPIO9: J1.21 (MISO0/GPIO9), J2.21 (MISO0/GPIO9)
/GPIO10: J1.19 (MOSI0/GPIO10), J2.19 (MOSI0/GPIO10)
/GPIO11: J1.23 (SCLK0/GPIO11), J2.23 (SCLK0/GPIO11)
/GPIO12: J1.32 (PWM0/GPIO12), J2.32 (PWM0/GPIO12)
/GPIO13: J1.33 (PWM1/GPIO13), J2.33 (PWM1/GPIO13)
/GPIO14: DS1.6 (E), J1.8 (GPIO14/TXD), J2.8 (GPIO14/TXD)
/GPIO15: DS1.4 (RS), J1.10 (GPIO15/RXD), J2.10 (GPIO15/RXD)
/GPIO16: DS1.11 (D4), J1.36 (GPIO16), J2.36 (GPIO16)
/GPIO17: DS1.12 (D5), J1.11 (GPIO17), J2.11 (GPIO17)
/GPIO18: DS1.13 (D6), J1.12 (GPIO18/PWM0), J2.12 (GPIO18/PWM0)
/GPIO19: DS1.14 (D7), J1.35 (GPIO19/MISO1), J2.35 (GPIO19/MISO1)
/GPIO20: J1.38 (GPIO20/MOSI1), J2.38 (GPIO20/MOSI1), J4.13 (POW), J4.14 (POW_dup)
/GPIO21: J1.40 (GPIO21/SCLK1), J2.40 (GPIO21/SCLK1), J4.11 (~E), J4.12 (~E_dup)
/GPIO22: J1.15 (GPIO22), J2.15 (GPIO22), J4.5 (S0)
/GPIO23: J1.16 (GPIO23), J2.16 (GPIO23), J4.7 (S1)
/GPIO24: J1.18 (GPIO24), J2.18 (GPIO24), J4.9 (S2)
/GPIO25: J1.22 (GPIO25), J2.22 (GPIO25), J4.6 (S3)
/GPIO26: J1.37 (GPIO26), J2.37 (GPIO26), J4.8 (S4)
/GPIO27: J1.13 (GPIO27), J2.13 (GPIO27), J4.10 (S5)
GND: DS1.1 (VSS), DS1.5 (R/W), DS1.16 (LED(-)), H1.1, H2.1, H3.1, H4.1, J1.6 (GND), J1.9 (GND), J1.14 (GND), J1.20 (GND), J1.25 (GND), J1.30 (GND), J1.34 (GND), J1.39 (GND), J2.6 (GND), J2.9 (GND), J2.14 (GND), J2.20 (GND), J2.25 (GND), J2.30 (GND), J2.34 (GND), J2.39 (GND), J3.1, J4.3 (GND), J4.4 (GND2), J4.15 (GND3), J4.16 (GND4), J5.1 (GND), J5.2 (GND2), J5.5 (GND3), J5.6 (GND4), J5.7 (GND5), J5.8 (GND6), J5.16 (GND3), RV1.1
unnamed: DS1.3 (VO), RV1.2

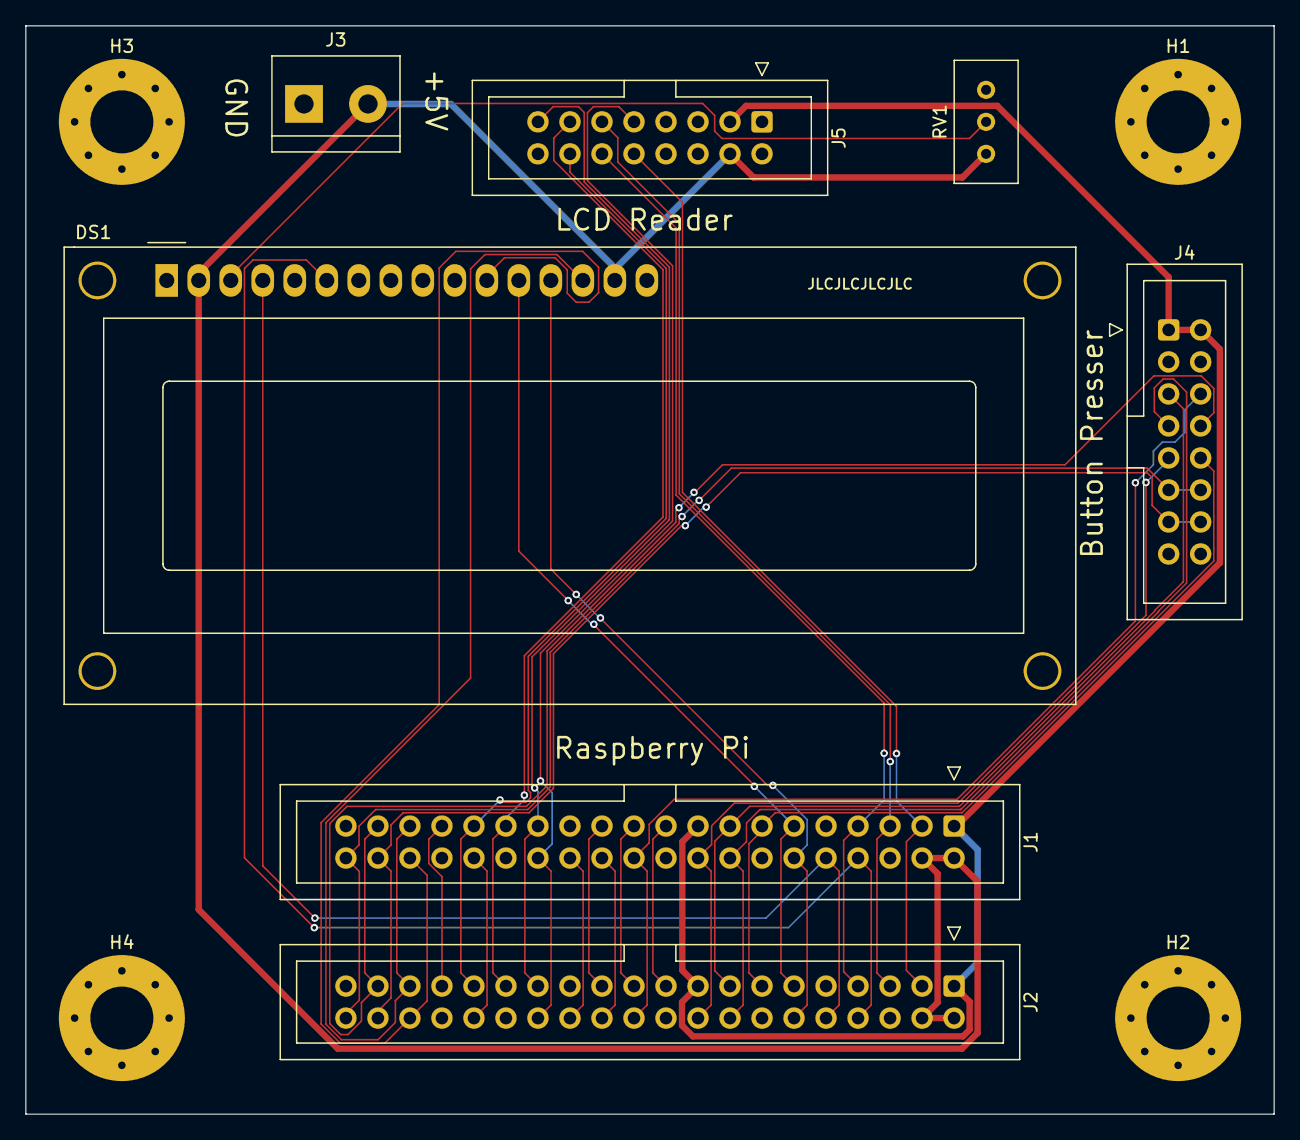
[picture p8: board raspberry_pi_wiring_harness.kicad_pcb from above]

Board: 2 copper layers, 99.1 x 86.4 mm, 11 parts (0 on the bottom side), 32 nets.

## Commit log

2022-07-22 first draft of arduino code
2022-07-31 driver for lcd shift registers
2022-07-31 pcb for calculator interface
    [calculator_interface.kicad_pcb, calculator_interface.kicad_sch, keypad.kicad_sch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]
2022-07-31 add mounting holes
    [calculator_interface.kicad_pcb, calculator_interface.kicad_sch, keypad.kicad_sch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]
2022-07-31 draft ready for final review
    [calculator_interface-B_Cu.gbr, calculator_interface-B_Mask.gbr, calculator_interface-B_Silkscreen.gbr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]
2022-08-01 remove flipped version
    [calculator_interface_flipped.kicad_pcb]
2022-08-02 changed reference voltage circuit to be compatible with voltage regulator
    [calculator_interface-B_Cu.gbr, calculator_interface-B_Mask.gbr, calculator_interface-B_Silkscreen.gbr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]
2022-12-22 all wired up
    [button_presser-B_Mask.gbr, button_presser-B_Paste.gbr, button_presser-B_Silkscreen.gbr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]
2022-12-22 sort pico code
2022-12-25 driver for lcd display
2022-12-25 initial calculator drivers
2023-01-19 speed up button presses
2023-01-20 tidying, better printing
2023-01-20 package up driver code
2023-01-23 do not track the database in git
2023-01-26 button names should align with emulator
2023-01-27 make the calculator more patient
2023-02-01 be more patient to ensure display has updated
2023-02-03 power off the calculator between sessions
